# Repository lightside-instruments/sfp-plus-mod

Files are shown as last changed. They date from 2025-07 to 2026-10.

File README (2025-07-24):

sfp-plus-mod is an open hardware SFP+
breakout module board published by Lightside Instruments AS.

Up to release sfp-plus-mod-1.3 the project provided schematics and
PCB design files for KiCAD. Since sfp-plus-mod-1.3-1
OpenSCAD design of a 3d printable mechanical enclosure conforming
with minor exceptions to SFF-8432 Rev 5.2a
was added - mechanical.scad.

The project is published by Lightside Instruments AS
under TAPR Open Hardware License. Read the LICENSE file
for details.

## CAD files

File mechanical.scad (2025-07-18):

$fn=50*1.0;

//SFF-8432 Rev 5.2a partial params

e=13.55; //module Width
s=8.55; //module Height
t=66.5; //Corrected for sfp-plus-module-1.3 //47.50; //Distance from positive stop to rear of module
k=3.25; //Height of module kick-out spring area
m=2.25; //Distance from bottom of module to printed circuit board
n=2.00; //Distance from rear shoulder to printed circuit board
n_error=0.25;
y=11.90; //Module width of bottom opening


//extension part parameters
e2=24;
t2=8.5;

corner_r=0.4;
union()
{
  difference()
  {
    //cube(size = [e,s,t], center = true);
    hull() {
      translate([-e/2+corner_r,s/2-corner_r,-t/2])
        cylinder(r=corner_r, h=t, $fn=100);
      translate([e/2-corner_r,s/2-corner_r,-t/2])
        cylinder(r=corner_r, h=t, $fn=100);
      translate([-e/2+corner_r,-s/2+corner_r,-t/2])
        cylinder(r=corner_r, h=t, $fn=100);
      translate([e/2-corner_r,-s/2+corner_r,-t/2])
        cylinder(r=corner_r, h=t, $fn=100);
    }
    cube(size = [10.00,s-4,t+1], center = true);
    translate([0,-s/2+n+0.8/2,0]) //
      cube(size = [12.00+0.1,0.8+2*n_error,t+1], center = true);

    translate([0,-s/2-1,-t/2+3])
    rotate([-70,0,0])
      cube(size = [e+0.1,s+0.1,2], center = true);

    translate([0,-4,-t/2+10/2])
      cube(size = [12+0.1,s+0.1,10+0.1], center = true);
  }

  // extension
  translate([0,0,(t+t2)/2])
    difference()
  {
    //cube(size = [e,s,t], center = true);
    hull() {
      translate([-e2/2+corner_r,s/2-corner_r,-t2/2])
        cylinder(r=corner_r, h=t2, $fn=100);
      translate([e2/2-corner_r,s/2-corner_r,-t2/2])
        cylinder(r=corner_r, h=t2, $fn=100);
      translate([-e2/2+corner_r,-s/2+corner_r,-t2/2])
        cylinder(r=corner_r, h=t2, $fn=100);
      translate([e2/2-corner_r,-s/2+corner_r,-t2/2])
        cylinder(r=corner_r, h=t2, $fn=100);
    }
    cube(size = [10.00,s-4,t2+1], center = true);
    translate([0,-s/2+n+0.8/2,0]) //
      cube(size = [22.00+0.4,0.8+2*n_error,t2+1], center = true);

    rotate([90,0,0])
      translate([6,0.75,(-s-0.1)/2])
        cylinder(r=2.5/2, h=s+0.1, $fn=100);

    rotate([90,0,0])
      translate([-6,0.75,(-s-0.1)/2])
        cylinder(r=2.5/2, h=s+0.1, $fn=100);
  }
}

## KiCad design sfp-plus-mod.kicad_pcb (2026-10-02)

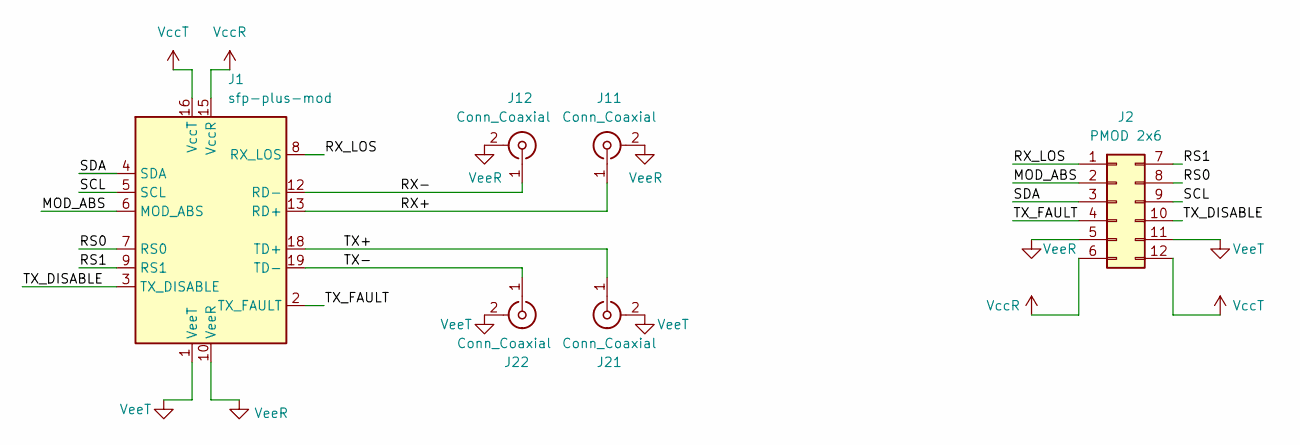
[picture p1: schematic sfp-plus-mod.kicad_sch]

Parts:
J1: sfp-plus-mod
J2: PMOD 2x6; PinSocket_2x06_P2.54mm_Vertical_1to6_7to12
J11, J12, J21: Conn_Coaxial; SMA_Wurth_60312002114503_Vertical
J22: Conn_Coaxial; SMA_Amphenol_901-144_Vertical

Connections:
/MOD_ABS: J1.6 (MOD_ABS), J2.2
/RS0: J1.7 (RS0), J2.8
/RS1: J1.9 (RS1), J2.7
/RX+: J1.13 (RD+), J11.1 (In)
/RX-: J1.12 (RD-), J12.1 (In)
/RX_LOS: J1.8 (RX_LOS), J2.1
/SCL: J1.5 (SCL), J2.9
/SDA: J1.4 (SDA), J2.3
/TX+: J1.18 (TD+), J21.1 (In)
/TX-: J1.19 (TD-), J22.1 (In)
/TX_DISABLE: J1.3 (TX_DISABLE), J2.10
/TX_FAULT: J1.2 (TX_FAULT), J2.4
VccR: J1.15 (VccR), J2.6
VccT: J1.16 (VccT), J2.12
VeeR: J1.10 (VeeR), J1.11 (VeeR), J1.14 (VeeR), J2.5, J11.2 (Ext), J12.2 (Ext)
VeeT: J1.1 (VeeT), J1.17 (VeeT), J1.20 (VeeT), J2.11, J21.2 (Ext), J22.2 (Ext)

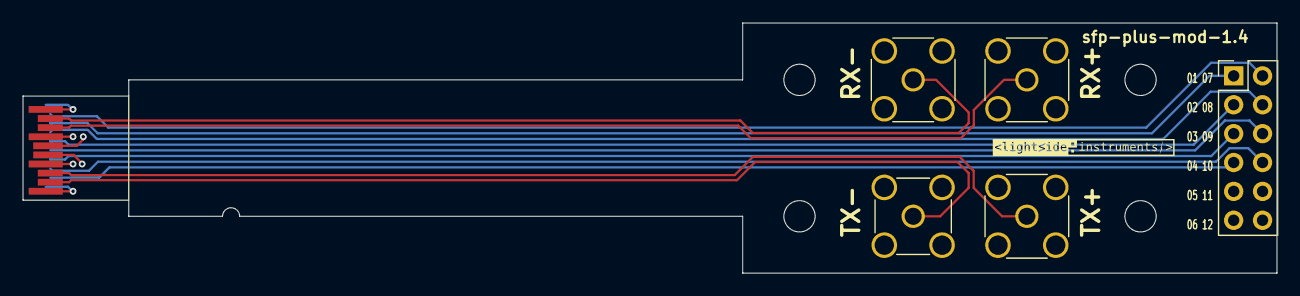
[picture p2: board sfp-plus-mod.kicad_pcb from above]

Board: 4 copper layers, 110.3 x 22.0 mm, 7 parts (0 on the bottom side), 16 nets.

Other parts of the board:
svg2mod: G***; lsi-logo-16mm

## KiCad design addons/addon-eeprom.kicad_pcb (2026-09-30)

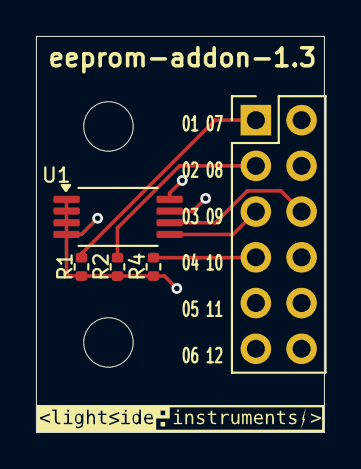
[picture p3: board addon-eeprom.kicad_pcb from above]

Board: 4 copper layers, 16.0 x 22.0 mm, 6 parts (0 on the bottom side), 7 nets.

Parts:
J2: PMOD 2x6; PinSocket_2x06_P2.54mm_Vertical_1to6_7to12
R1, R2, R4: R; R_0402_1005Metric
U1: AT24CS02-XHM; TSSOP-8_4.4x3mm_P0.65mm
svg2mod: G***; lsi-logo-16mm

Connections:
/MOD_ABS: J2.2, R2.2
/RX_LOS: J2.1, R1.2
/SCL: J2.9, U1.6 (SCL)
/SDA: J2.3, U1.5 (SDA)
/TX_FAULT: J2.4, R4.2
GND: J2.5, J2.11, R1.1, R2.1, R4.1, U1.1 (A0), U1.2 (A1), U1.3 (A2), U1.4 (GND), U1.7 (WP)
VCC: J2.6, J2.12, U1.8 (VCC)
